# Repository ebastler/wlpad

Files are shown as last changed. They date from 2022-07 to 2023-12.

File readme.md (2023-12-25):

# wlpad
wlpad is a simple wireless numpad, designed around a moko MK08A module, and fitting both Hi-Tek 725 as well as MX switches. While the PCB is the same for both switch types, the plate is different.

### Features
* Runs ZMK firmware on a Moko MK08A module - firmware can be found in my [zmk-config](https://github.com/ebastler/zmk-config) repo
* Hi-Tek 725 and Cherry MX compatibility
* Molex Picoblade connectors for battery and plate connection
* Charge indicator LED, some WS2812_2020 and a small 128x32px OLED can be placed on the plate

This PCB was painly made as a proof-of-concept for my Hi-Tek 725 footprints, and to try the MK08A module and MAX17048 fuel gauge chip on an actual PCB. The latter already found its way into my [Osprey](https://github.com/ebastler/osprey). 

rc1.0 had some issues (vertical 2u keys rotated by 180°, LEDs on plate connected to GND instead of VDD), which were addressed by the current rc1.1 version. However, the rc1.1 version has not been (and probably will not be) prototyped - use at your own risk. Please report back if you successfully tested such a PCB.

### Renders (rc1.1)
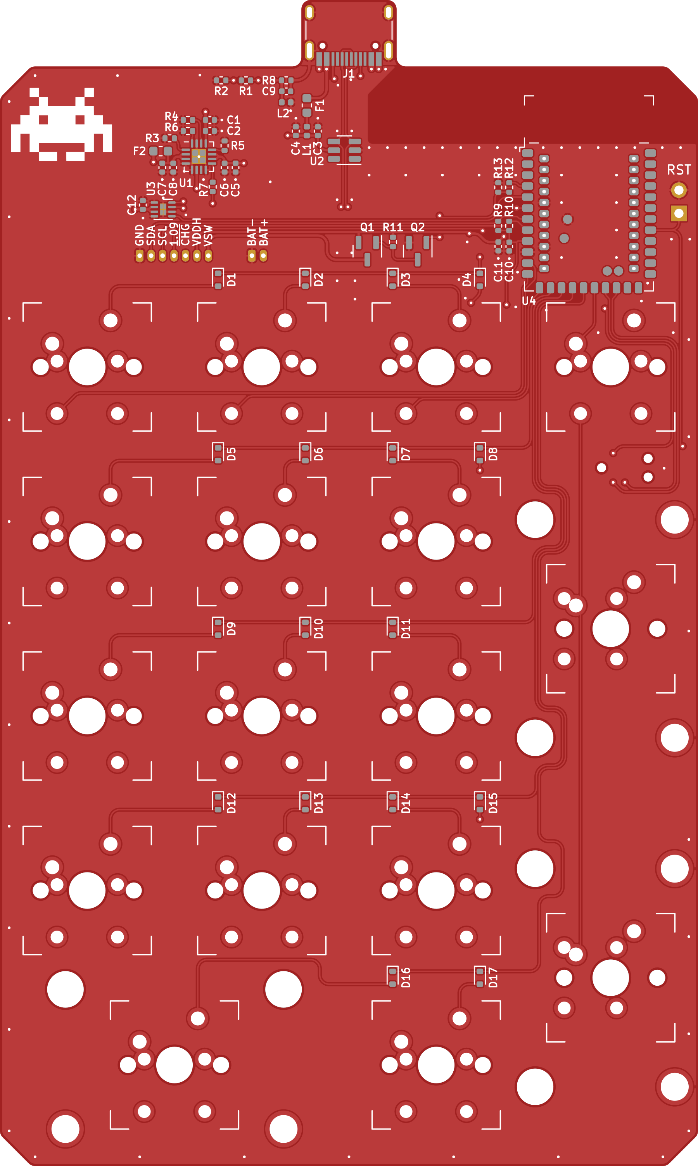
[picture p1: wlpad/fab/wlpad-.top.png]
topside
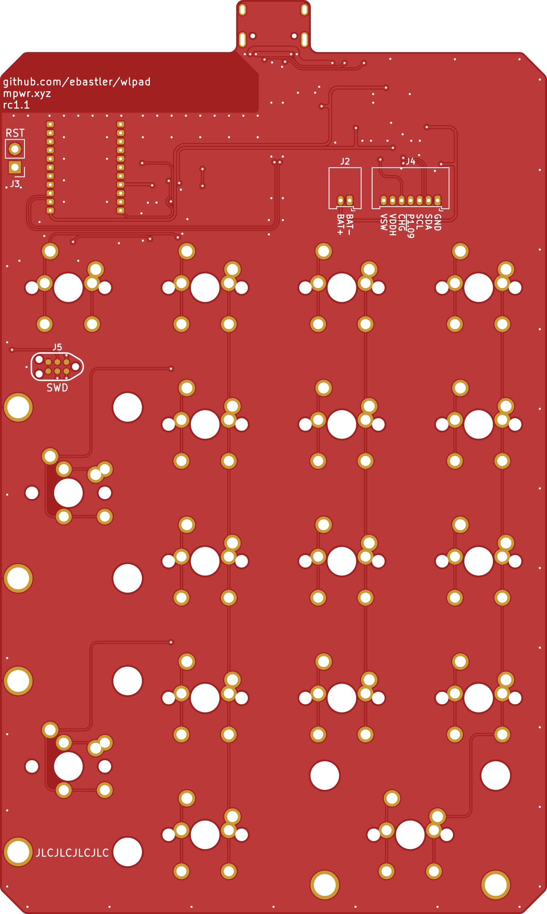
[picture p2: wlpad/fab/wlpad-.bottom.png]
 

### Pixtures (rc1.0)
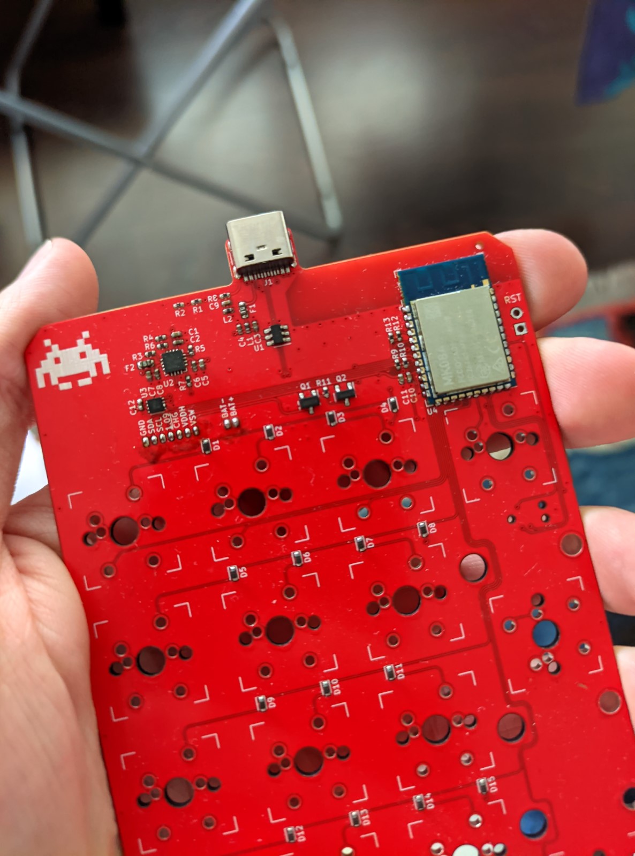
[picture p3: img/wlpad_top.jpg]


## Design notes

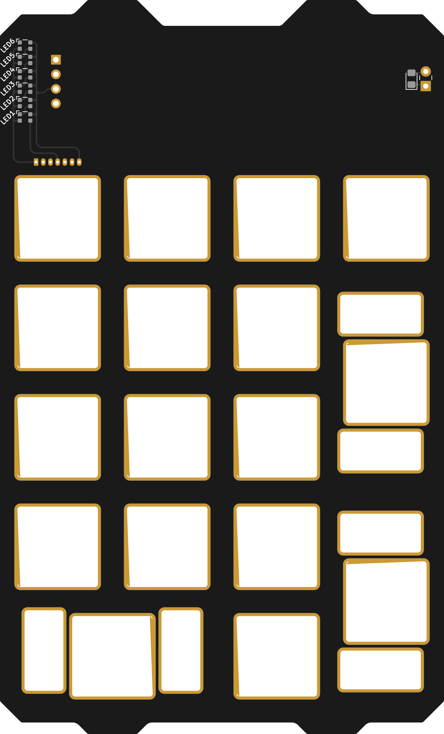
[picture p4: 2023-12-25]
plate-MX/fab/plate-MX-.top.png

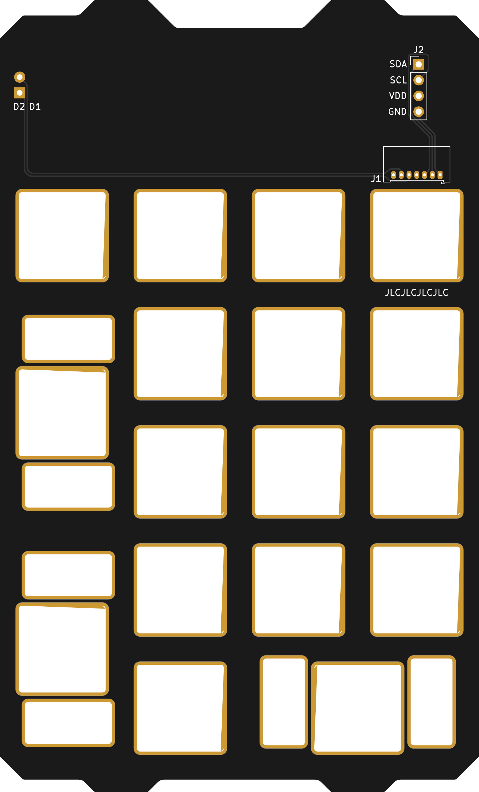
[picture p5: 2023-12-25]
plate-MX/fab/plate-MX-.bottom.png

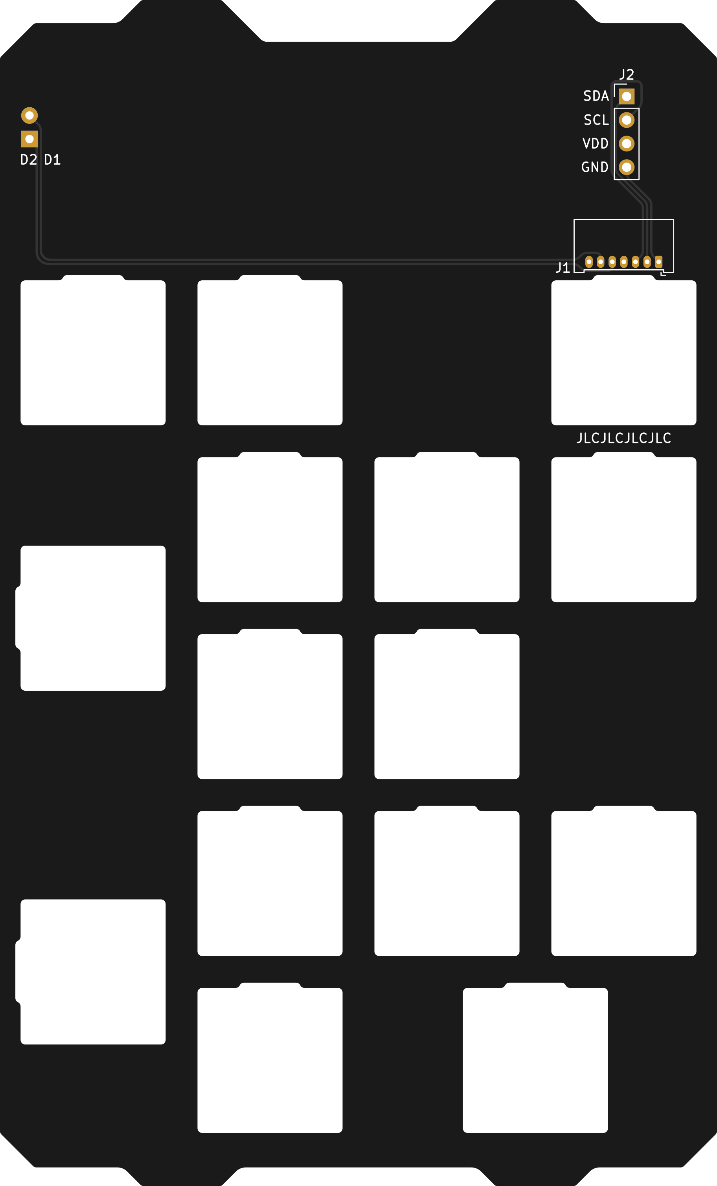
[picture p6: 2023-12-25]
plate-SI/fab/plate-SI-.bottom.png

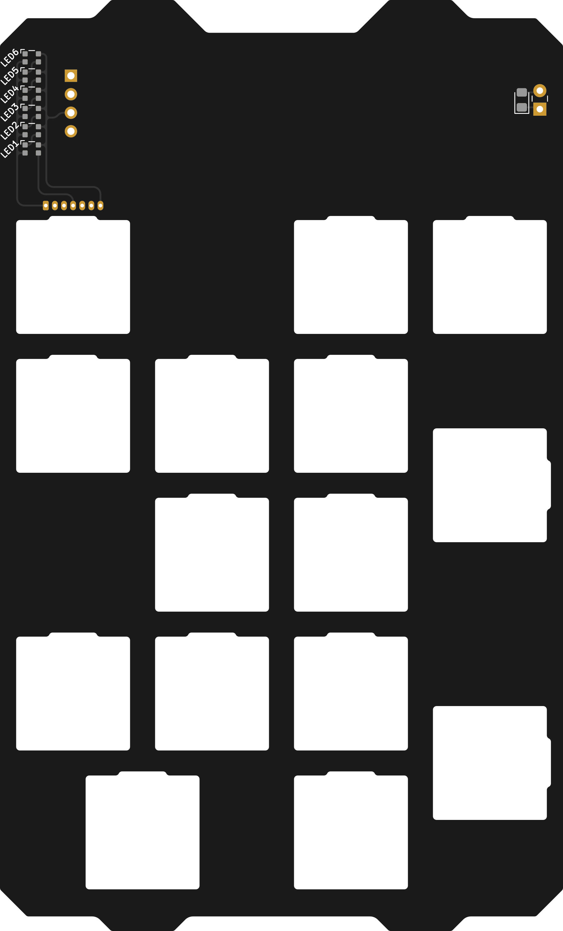
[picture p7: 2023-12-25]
plate-SI/fab/plate-SI-.top.png

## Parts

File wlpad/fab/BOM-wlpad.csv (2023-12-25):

Comment | Designator | Footprint | LCSC
AO3401A | Q1 | SOT-23 | C15127
USB_C_Receptacle_USB2.0 | J1 | USB_C_Receptacle_HRO_TYPE-C-31-M-12 | C165948
500mA | F1,F2 | Fuse_0603_1608Metric | C210357
4.7u | C1,C3,C5,C7 | C_0402_1005Metric | C23733
100R | R12 | R_0402_1005Metric | C25076
10k | R11,R13,R3,R6,R7 | R_0402_1005Metric | C25744
22k | R4 | R_0402_1005Metric | C25792
2k2 | R5 | R_0402_1005Metric | C25867
5k1 | R1,R10,R2,R9 | R_0402_1005Metric | C25905
1M | R8 | R_0402_1005Metric | C26083
MAX17048 | U3 | DFN-8-1EP_2x2mm_P0.5mm_EP0.7x1.3mm | C2682616
BQ24075RGT | U1 | VQFN-16-1EP_3x3mm_P0.5mm_EP1.6x1.6mm | C2865459
1N4148WT | D1,D10,D11,D12,D13,D14,D15,D16,D17,D2,D3,D4,D5,D6,D7,D8,D9 | D_SOD-523 | C511874
100n | C10,C11,C12,C2,C4,C6,C8,C9 | C_0402_1005Metric | C52923
SRV05-4 | U2 | SOT-23-6 | C558418
2N7002 | Q2 | SOT-23 | C8545
BLM15PX121SN1D | L1,L2 | L_0402_1005Metric | C88970
ext | J4 | Molex_PicoBlade_53048-0710_1x07_P1.25mm_Horizontal
BAT | J2 | Molex_PicoBlade_53048-0210_1x02_P1.25mm_Horizontal

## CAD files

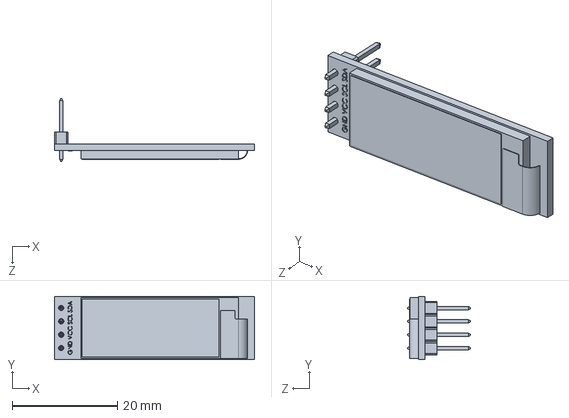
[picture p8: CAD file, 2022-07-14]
3d/128x32-OLED.STEP
38.0 x 12.0 x 11.9 mm

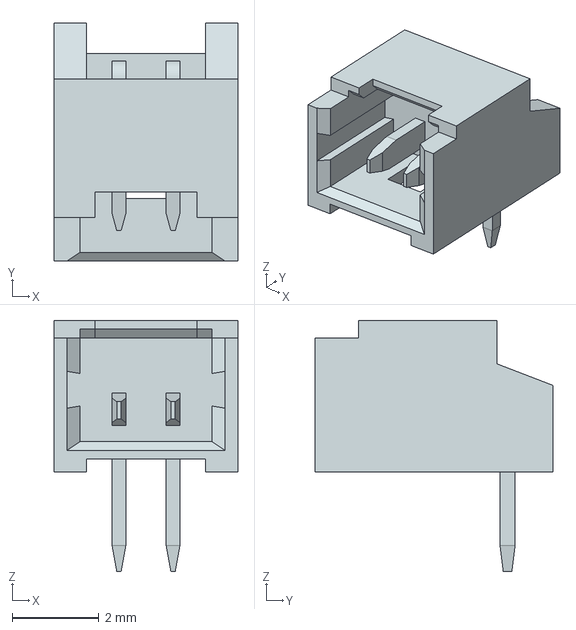
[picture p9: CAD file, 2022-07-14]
3d/530480260.stp
4.25 x 5.50 x 5.80 mm

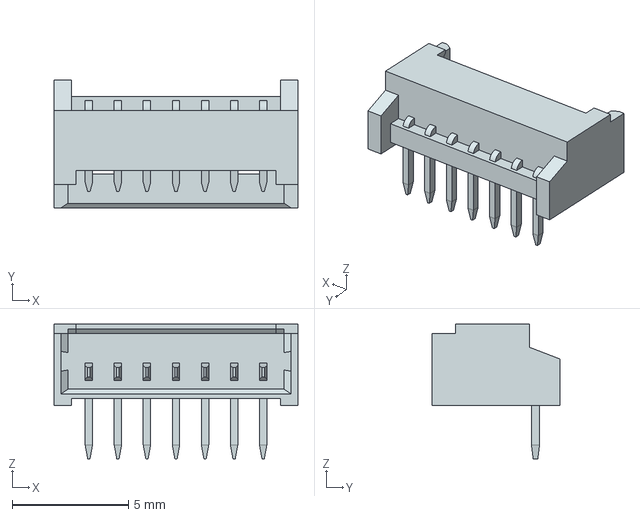
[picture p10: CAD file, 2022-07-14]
3d/530480760.stp
10.5 x 5.50 x 5.80 mm

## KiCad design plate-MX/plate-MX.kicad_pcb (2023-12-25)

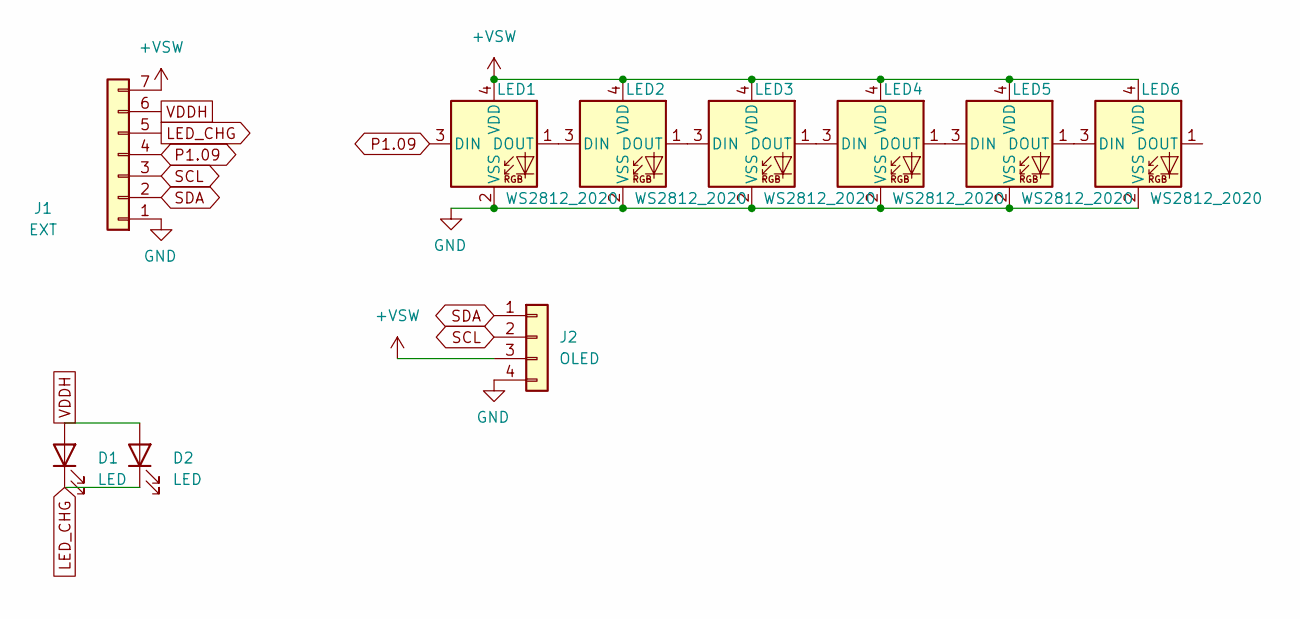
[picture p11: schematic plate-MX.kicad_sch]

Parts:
D1: LED; LED_0805_2012Metric_Pad1.15x1.40mm_HandSolder
D2: LED; LED_Rectangular_W3.0mm_H2.0mm
J1: EXT; Molex_PicoBlade_53048-0710_1x07_P1.25mm_Horizontal
J2: OLED; PinHeader_1x04_P2.54mm_Vertical
LED1, LED2, LED3, LED4, LED5, LED6: WS2812_2020; LED_WS2812_2020

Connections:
+VSW: J1.7, J2.3, LED1.4 (VDD), LED2.4 (VDD), LED3.4 (VDD), LED4.4 (VDD), LED5.4 (VDD), LED6.4 (VDD)
GND: J1.1, J2.4, LED1.2 (VSS), LED2.2 (VSS), LED3.2 (VSS), LED4.2 (VSS), LED5.2 (VSS), LED6.2 (VSS)
LED_CHG: D1.1 (K), D2.1 (K), J1.5
unnamed: LED1.1 (DOUT), LED2.3 (DIN)
unnamed: LED2.1 (DOUT), LED3.3 (DIN)
unnamed: LED3.1 (DOUT), LED4.3 (DIN)
unnamed: LED4.1 (DOUT), LED5.3 (DIN)
unnamed: LED5.1 (DOUT), LED6.3 (DIN)
P1.09: J1.4, LED1.3 (DIN)
SCL: J1.3, J2.2
SDA: J1.2, J2.1
VDDH: D1.2 (A), D2.2 (A), J1.6

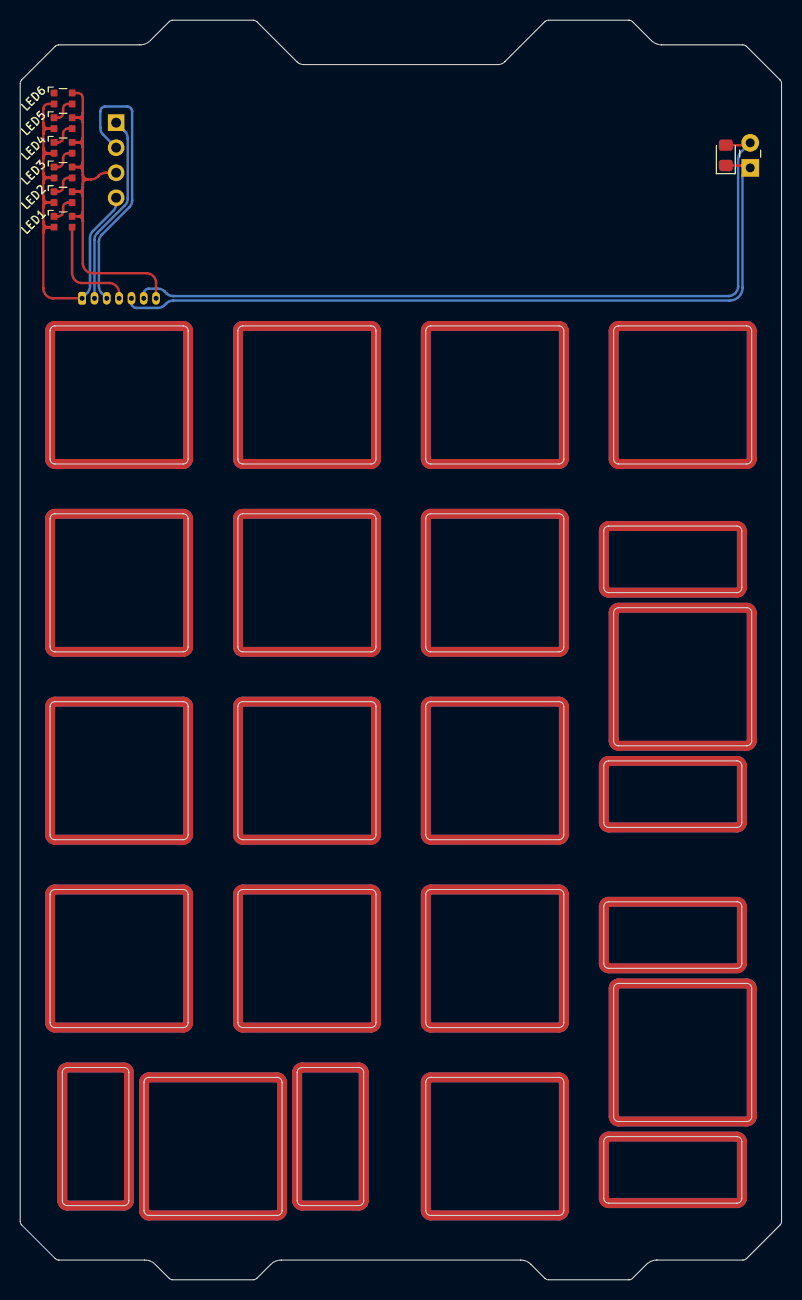
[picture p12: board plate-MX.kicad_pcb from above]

Board: 2 copper layers, 77.2 x 127.7 mm, 10 parts (1 on the bottom side), 12 nets.

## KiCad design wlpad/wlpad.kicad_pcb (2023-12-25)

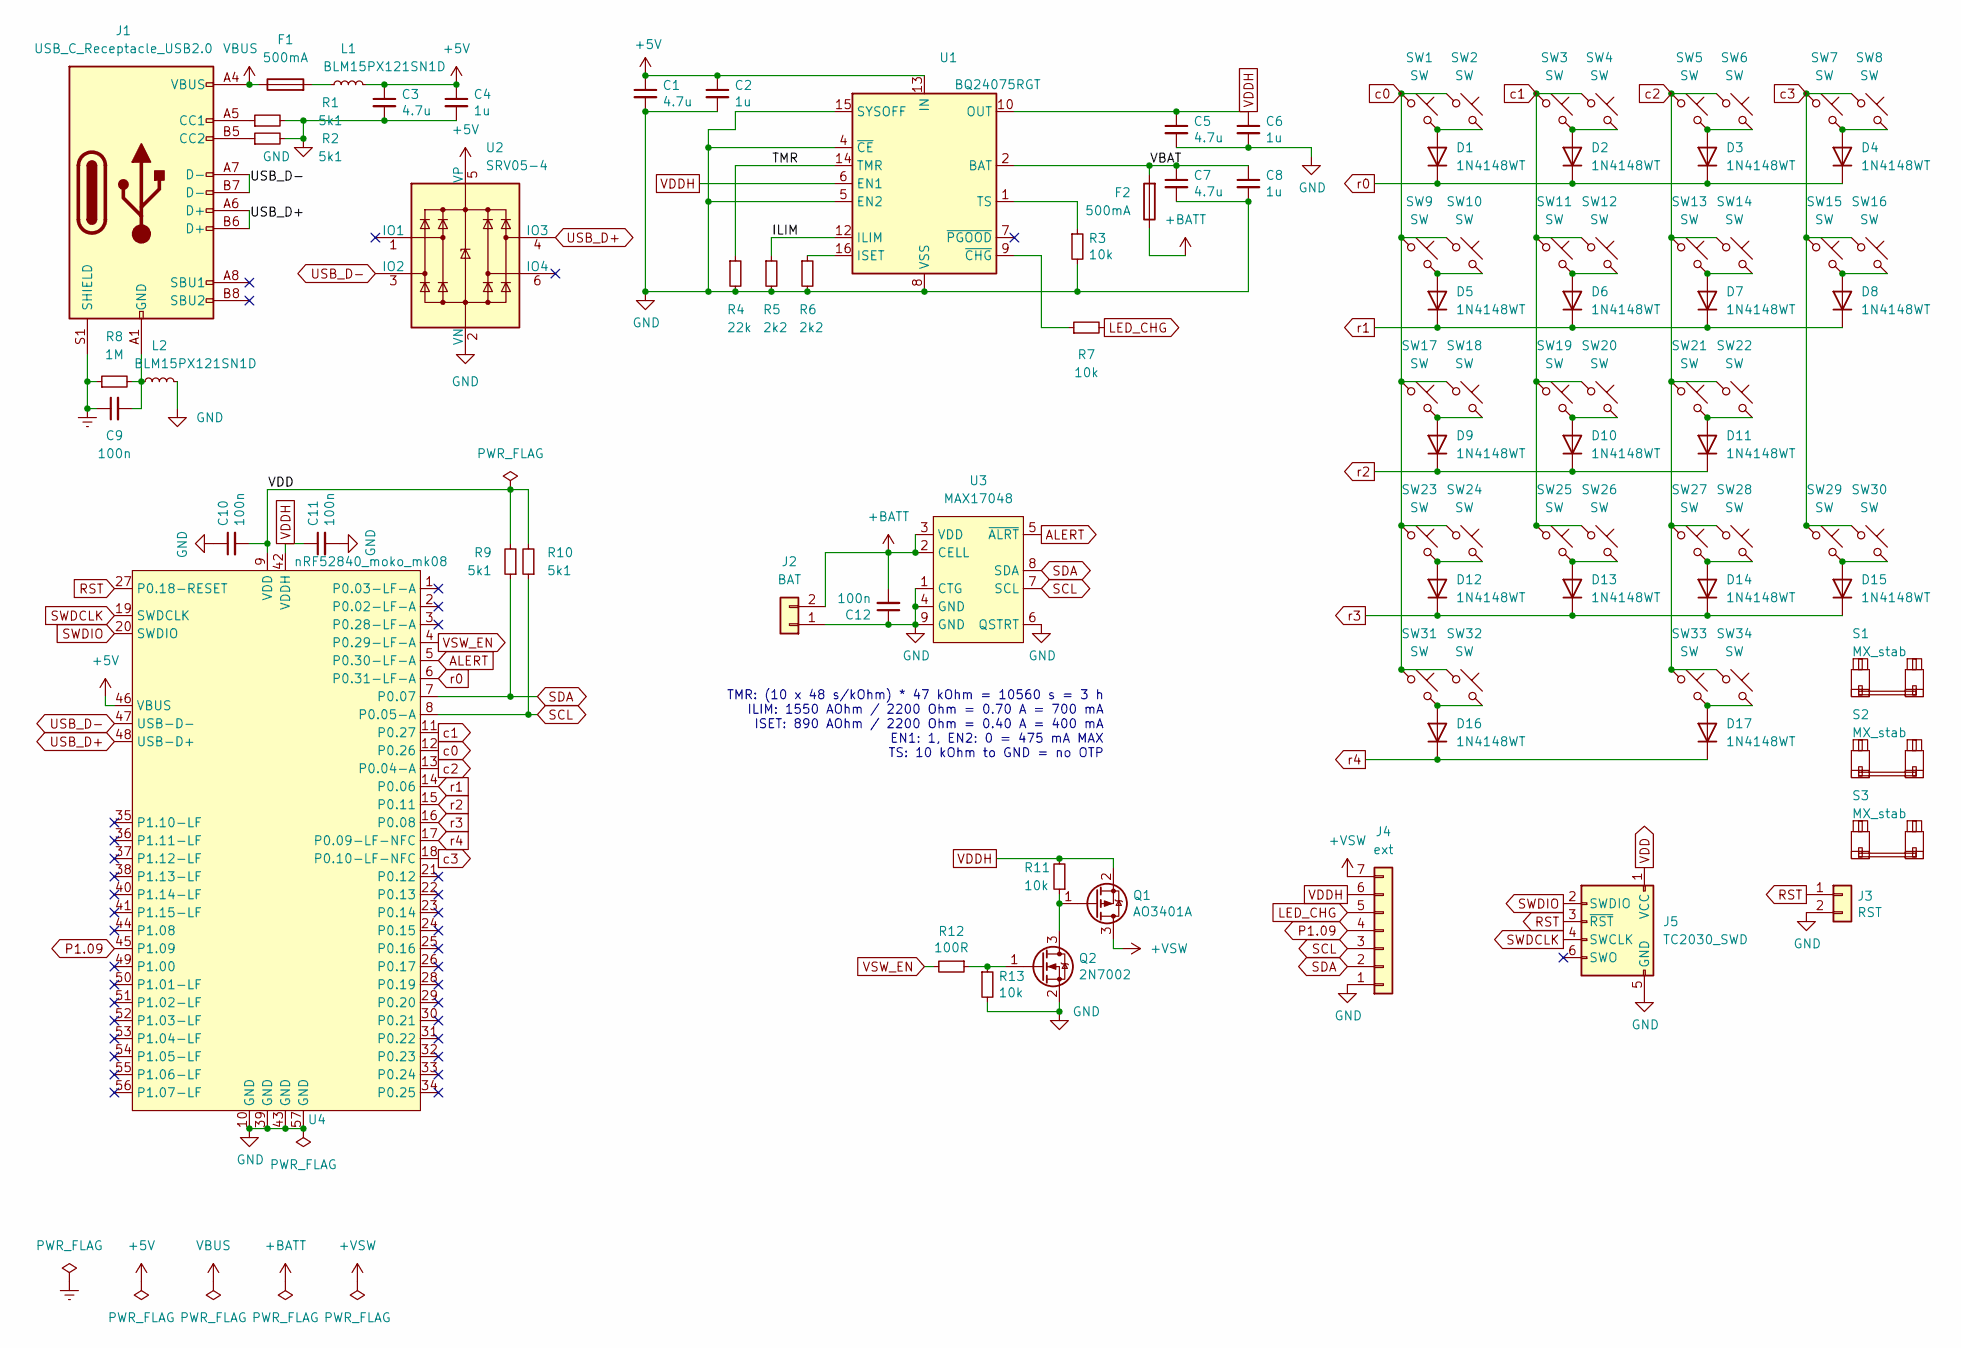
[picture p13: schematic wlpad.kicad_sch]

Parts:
C1, C3, C5, C7: 4.7u; C_0402_1005Metric; LCSC C23733
C2, C4, C6, C8: 1u; C_0402_1005Metric; LCSC C52923
C9: 100n; C_0402_1005Metric
C10, C11, C12: 100n; C_0402_1005Metric; LCSC C52923
D1, D2, D3, D4, D5, D6, D7, D8, D9, D10, D11, D12, D13, D14, D15, D16, D17: 1N4148WT; D_SOD-523
F1, F2: 500mA; Fuse_0603_1608Metric
J1: USB_C_Receptacle_USB2.0; USB_C_Receptacle_HRO_TYPE-C-31-M-12
J2: BAT; Molex_PicoBlade_53048-0210_1x02_P1.25mm_Horizontal
J3: RST; PinHeader_1x02_P2.54mm_Vertical
J4: ext; Molex_PicoBlade_53048-0710_1x07_P1.25mm_Horizontal
J5: TC2030_SWD; CON_TC2030_outlined
L1, L2: BLM15PX121SN1D; L_0402_1005Metric; LCSC C88970
Q1: AO3401A; SOT-23
Q2: 2N7002; SOT-23
R1, R2, R9, R10: 5k1; R_0402_1005Metric
R3, R7: 10k; R_0402_1005Metric; LCSC C25744
R4: 22k; R_0402_1005Metric; LCSC C25792
R5: 2k2; R_0402_1005Metric; LCSC C25867
R6: 2k2; R_0402_1005Metric; LCSC C25744
R8: 1M; R_0402_1005Metric
R11, R13: 10k; R_0402_1005Metric
R12: 100R; R_0402_1005Metric
S1, S2, S3: MX_stab; STAB_MX_P_2u
SW1, SW3, SW5, SW7, SW9, SW11, SW13, SW15, SW17, SW19, SW21, SW23, SW25, SW27, SW29, SW31, SW33: SW; SW_HiTek_1u
SW2, SW4, SW6, SW8, SW10, SW12, SW14, SW16, SW18, SW20, SW22, SW24, SW26, SW28, SW30, SW32, SW34: SW; SW_MX_1u
U1: BQ24075RGT; VQFN-16-1EP_3x3mm_P0.5mm_EP1.6x1.6mm
U2: SRV05-4; SOT-23-6
U3: MAX17048; DFN-8-1EP_2x2mm_P0.5mm_EP0.7x1.3mm
U4: nRF52840_moko_mk08; nRF52840_moko_mk08_HS

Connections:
+5V: C1.1, C2.1, C3.1, C4.1, L1.2, U1.13 (IN), U2.5 (VP), U4.46 (VBUS)
+BATT: C12.2, F2.1, J2.2, U3.2 (CELL), U3.3 (VDD)
+VSW: J4.7, Q1.3 (D)
/ILIM: R5.1, U1.12 (ILIM)
/TMR: R4.1, U1.14 (TMR)
/VBAT: C7.1, C8.1, F2.2, U1.2 (BAT), U1.3 (BAT)
ALERT: U3.5 (~ALRT), U4.5 (P0.30-LF-A)
Earth: C9.1, J1.S1 (SHIELD), R8.1
GND: C1.2, C2.2, C3.2, C4.2, C5.2, C6.2, C7.2, C8.2, C10.1, C11.2, C12.1, J2.1, J3.2, J4.1, J5.5 (GND), L2.2, Q2.2 (S), R1.2, R2.2, R3.2, R4.2, R5.2, R6.2, R13.2, U1.4 (~CE), U1.5 (EN2), U1.8 (VSS), U1.15 (SYSOFF), U1.17 (VSS), U2.2 (VN), U3.1 (CTG), U3.4 (GND), U3.6 (QSTRT), U3.9 (GND), U4.10 (GND), U4.39 (GND), U4.43 (GND), U4.57 (GND)
LED_CHG: J4.5, R7.2
unnamed: C9.2, J1.A1 (GND), J1.A12 (GND), J1.B1 (GND), J1.B12 (GND), L2.1, R8.2
unnamed: D1.2 (A), SW1.2, SW2.2
unnamed: D2.2 (A), SW3.2, SW4.2
unnamed: D3.2 (A), SW5.2, SW6.2
unnamed: D4.2 (A), SW7.2, SW8.2
unnamed: D5.2 (A), SW9.2, SW10.2
unnamed: D6.2 (A), SW11.2, SW12.2
unnamed: D7.2 (A), SW13.2, SW14.2
unnamed: D8.2 (A), SW15.2, SW16.2
unnamed: D9.2 (A), SW17.2, SW18.2
unnamed: D10.2 (A), SW19.2, SW20.2
unnamed: D11.2 (A), SW21.2, SW22.2
unnamed: D12.2 (A), SW23.2, SW24.2
unnamed: D13.2 (A), SW25.2, SW26.2
unnamed: D14.2 (A), SW27.2, SW28.2
unnamed: D15.2 (A), SW29.2, SW30.2
unnamed: D16.2 (A), SW31.2, SW32.2
unnamed: D17.2 (A), SW33.2, SW34.2
unnamed: F1.2, L1.1
unnamed: J1.A5 (CC1), R1.1
unnamed: J1.B5 (CC2), R2.1
unnamed: Q1.1 (G), Q2.3 (D), R11.1
unnamed: Q2.1 (G), R12.1, R13.1
unnamed: R6.1, U1.16 (ISET)
unnamed: R3.1, U1.1 (TS)
unnamed: R7.1, U1.9 (~CHG)
P1.09: J4.4, U4.45 (P1.09)
RST: J3.1, J5.3 (~RST), U4.27 (P0.18-RESET)
SCL: J4.3, R10.1, U3.7 (SCL), U4.8 (P0.05-A)
SDA: J4.2, R9.1, U3.8 (SDA), U4.7 (P0.07)
SWDCLK: J5.4 (SWCLK), U4.19 (SWDCLK)
SWDIO: J5.2 (SWDIO), U4.20 (SWDIO)
USB_D+: J1.A6 (D+), J1.B6 (D+), U2.4 (IO3), U4.48 (USB-D+)
USB_D-: J1.A7 (D-), J1.B7 (D-), U2.3 (IO2), U4.47 (USB-D-)
VBUS: F1.1, J1.A4 (VBUS), J1.A9 (VBUS), J1.B4 (VBUS), J1.B9 (VBUS)
VDD: C10.2, J5.1 (VCC), R9.2, R10.2, U4.9 (VDD)
VDDH: C5.1, C6.1, C11.1, J4.6, Q1.2 (S), R11.2, U1.6 (EN1), U1.10 (OUT), U1.11 (OUT), U4.42 (VDDH)
VSW_EN: R12.2, U4.4 (P0.29-LF-A)
c0: SW1.1, SW2.1, SW9.1, SW10.1, SW17.1, SW18.1, SW23.1, SW24.1, SW31.1, SW32.1, U4.12 (P0.26)
c1: SW3.1, SW4.1, SW11.1, SW12.1, SW19.1, SW20.1, SW25.1, SW26.1, U4.11 (P0.27)
c2: SW5.1, SW6.1, SW13.1, SW14.1, SW21.1, SW22.1, SW27.1, SW28.1, SW33.1, SW34.1, U4.13 (P0.04-A)
c3: SW7.1, SW8.1, SW15.1, SW16.1, SW29.1, SW30.1, U4.18 (P0.10-LF-NFC)
r0: D1.1 (K), D2.1 (K), D3.1 (K), D4.1 (K), U4.6 (P0.31-LF-A)
r1: D5.1 (K), D6.1 (K), D7.1 (K), D8.1 (K), U4.14 (P0.06)
r2: D9.1 (K), D10.1 (K), D11.1 (K), U4.15 (P0.11)
r3: D12.1 (K), D13.1 (K), D14.1 (K), D15.1 (K), U4.16 (P0.08)
r4: D16.1 (K), D17.1 (K), U4.17 (P0.09-LF-NFC)

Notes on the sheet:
TMR: (10 x 48 s/kOhm) * 47 kOhm = 10560 s = 3 h ILIM: 1550 AOhm / 2200 Ohm = 0.70 A = 700 mA ISET: 890 AOhm / 2200 Ohm = 0.40 A = 400 mA EN1: 1, EN2: 0 = 475 mA MAX TS: 10 kOhm to GND = no OTP

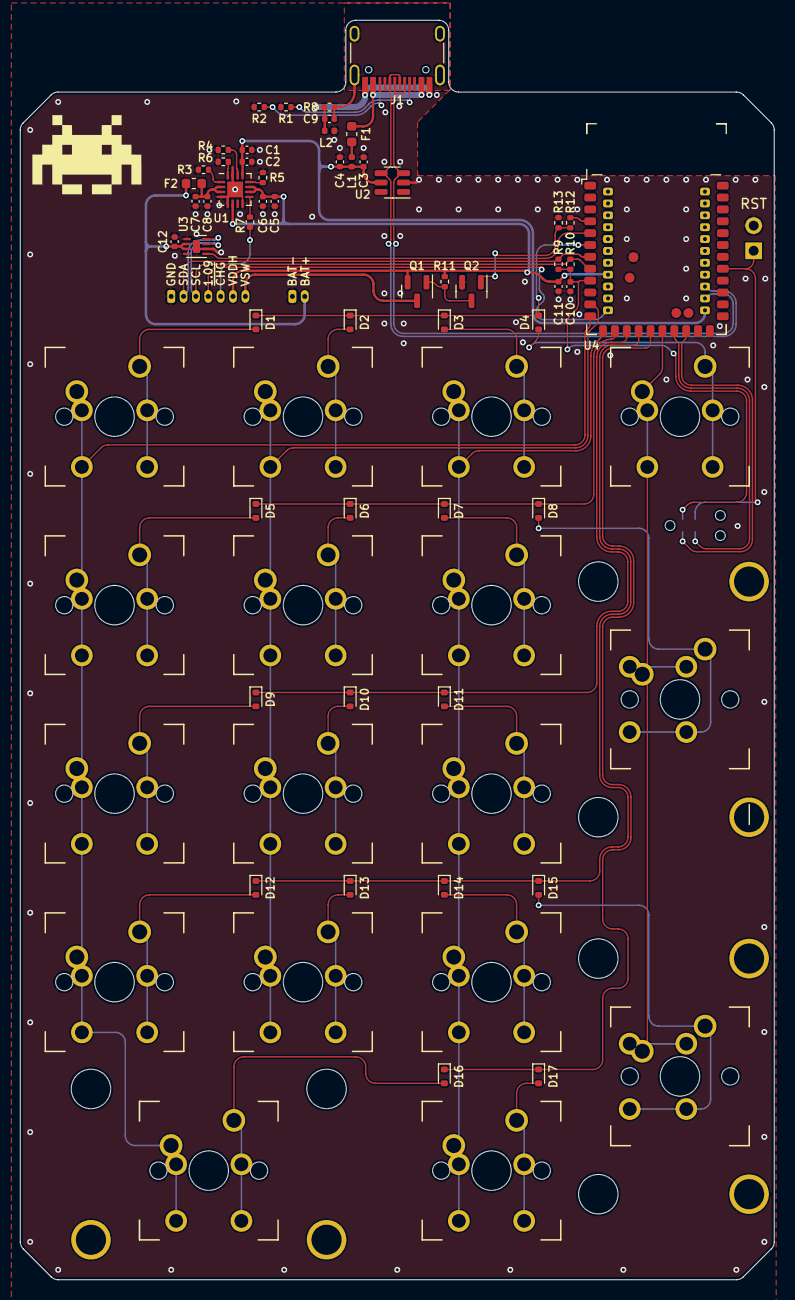
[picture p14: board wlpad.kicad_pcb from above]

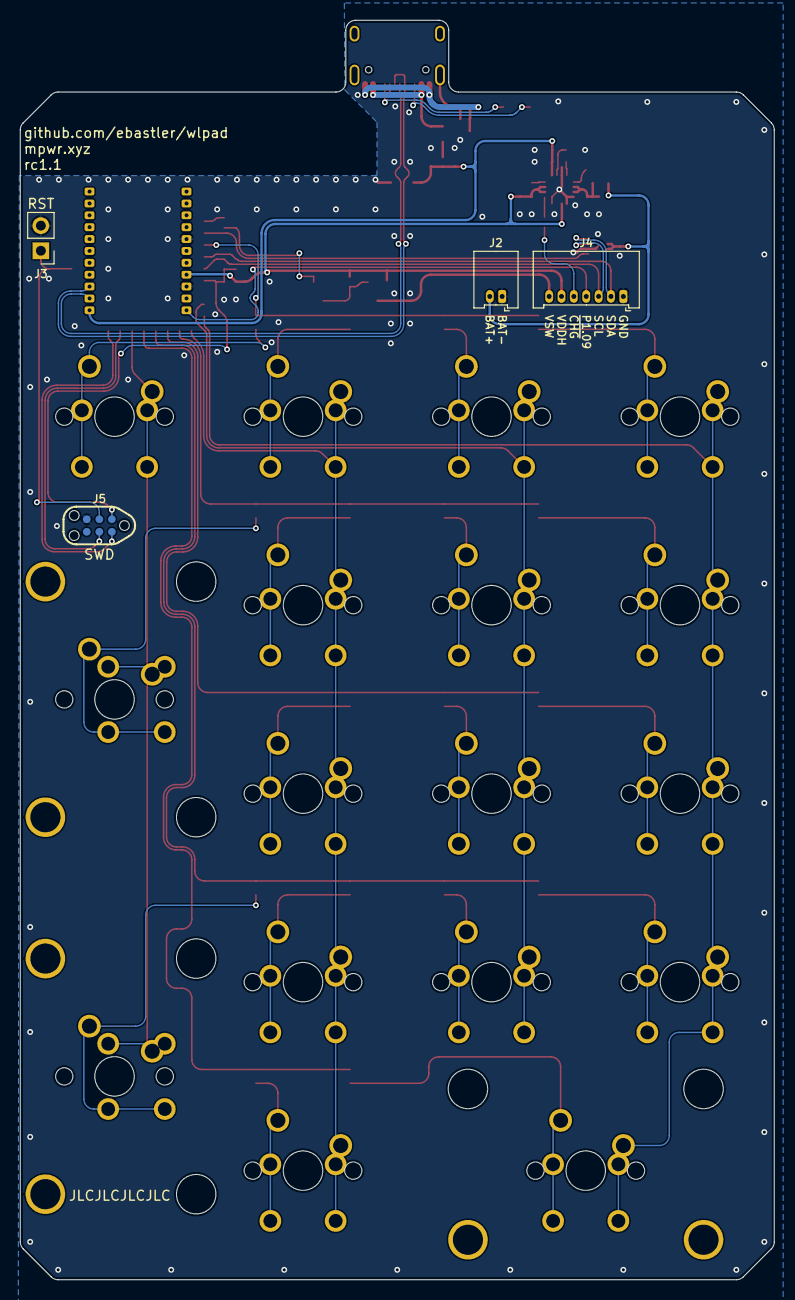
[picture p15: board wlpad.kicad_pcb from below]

Board: 2 copper layers, 76.2 x 127.3 mm, 94 parts (4 on the bottom side), 57 nets.

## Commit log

2022-07-14 first proto rev
    [128x32-OLED.STEP, 530480260.stp, 530480760.stp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]
2023-12-25 fixed wrong orientation of vertical 2u keys, renamed project folder, switched to PCM marbastlib
    [BOM-wlpad.csv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]
2023-12-25 fixed SI plate, added MX plate
    [plate-MX.kicad_pcb, plate-MX.kicad_sch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]
